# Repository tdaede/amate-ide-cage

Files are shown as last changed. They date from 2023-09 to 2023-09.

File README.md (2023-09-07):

This is a PCB for the NEC PC-9821 A-Mate series hard drive caddies, e.g. the NEC PC-9821A-E07 or ICM INTER-340A.

The PCB is mechanically compatible, though note that the IDE cable is reversed comapred to the NEC board! NEC uses a ribbon cable with the connector crimped on backwards. This PCB is instead marked for a standard, straight through IDE cable. The connector can still be installed reversed if desired, or a right angle connector could be used for e.g. a CF card adapter.

Also note that the 74HCT157s are in a narrow SO package rather than the more common SOIC.

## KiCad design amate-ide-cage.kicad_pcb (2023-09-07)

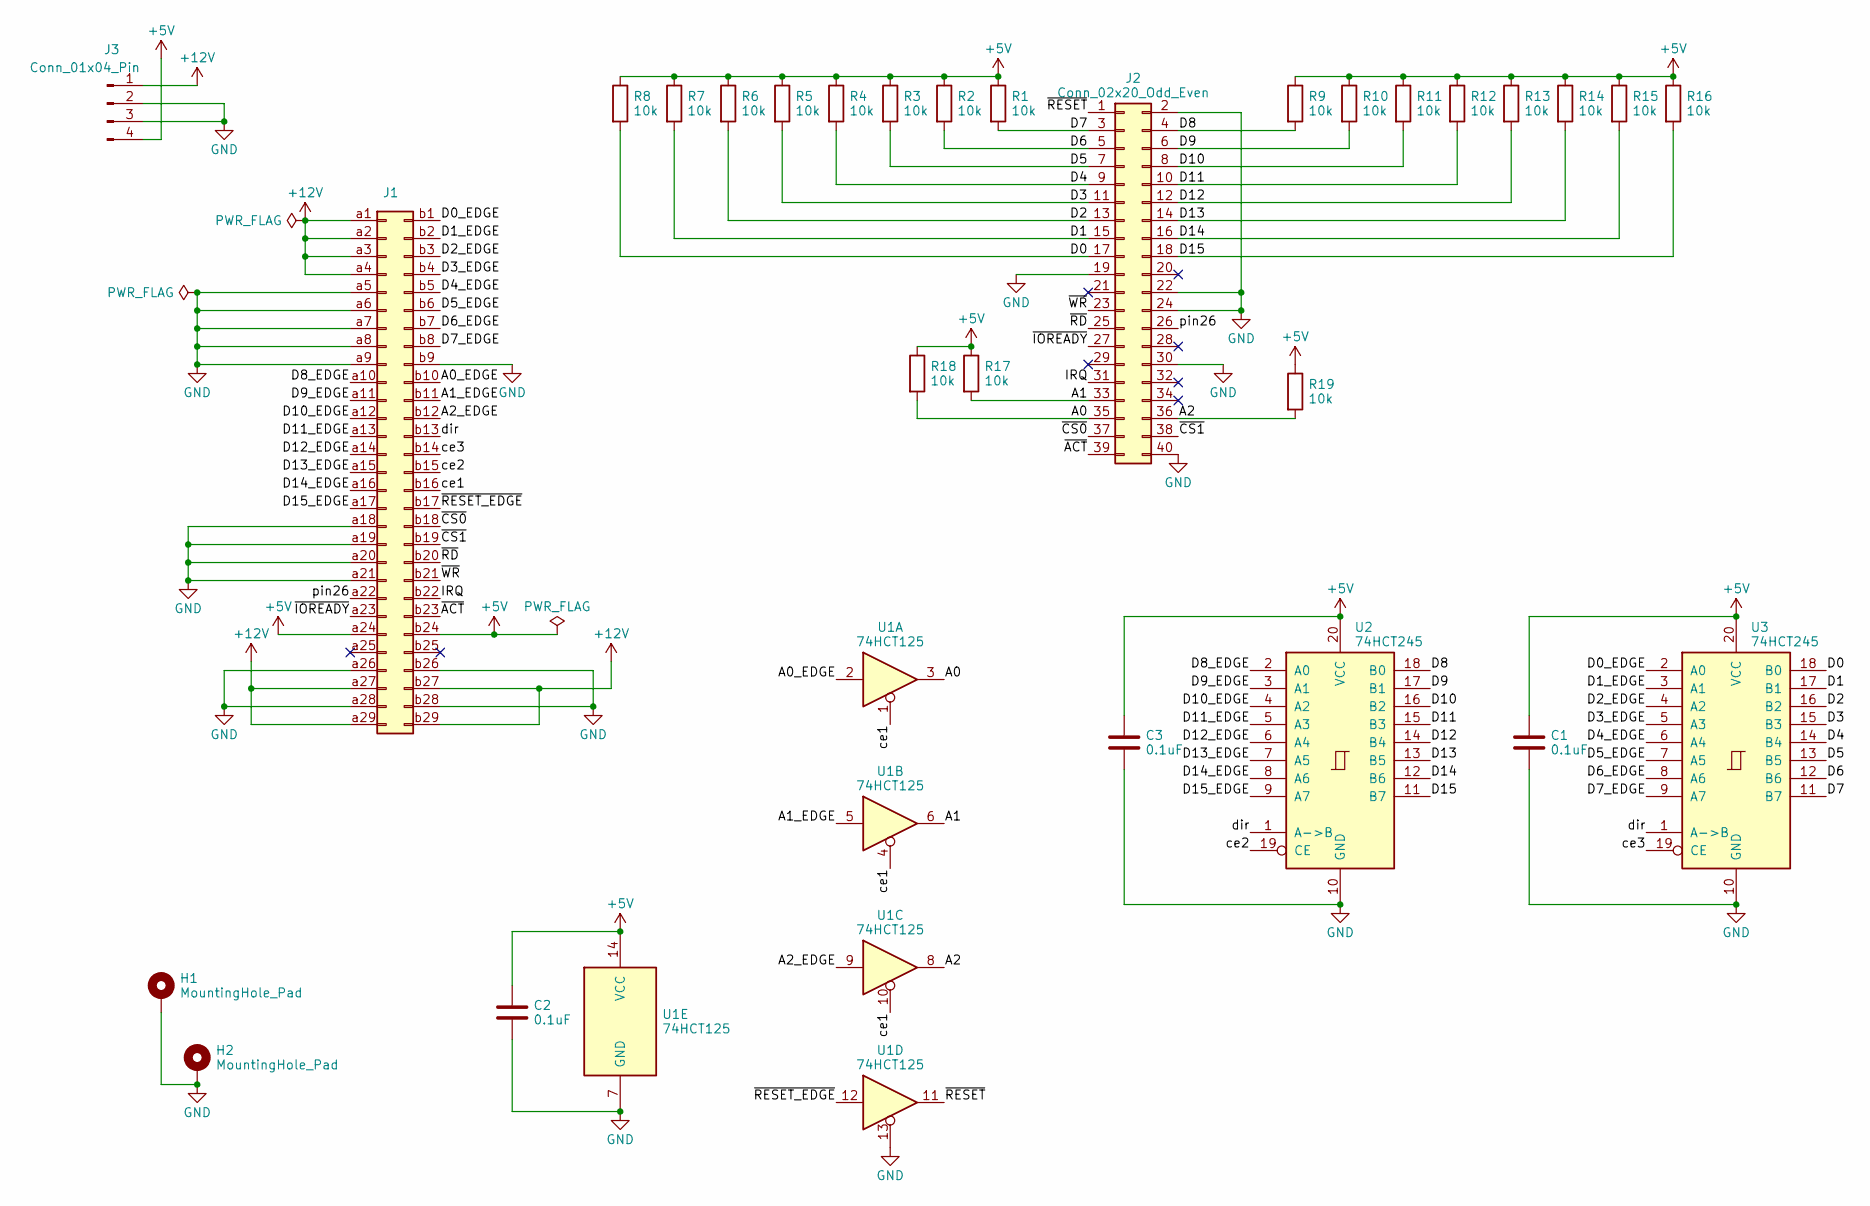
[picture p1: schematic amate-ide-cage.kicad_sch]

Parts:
C1, C2, C3: 0.1uF; C_0603_1608Metric; Digikey 311-1341-1-ND
H1, H2: MountingHole_Pad; MountingHole_3mm_Pad; Digikey DNP
J1: amate_ide_edge; Digikey DNP
J2: Conn_02x20_Odd_Even; IDC-Header_2x20_P2.54mm_Vertical; Digikey S9175-ND
J3: Conn_01x04_Pin; Molex_KK-396_5273-04A_1x04_P3.96mm_Vertical; Digikey WM4622-ND
R1, R2, R3, R4, R5, R6, R7, R8, R9, R10, R11, R12, R13, R14, R15, R16, R17, R18, R19: 10k; R_0603_1608Metric; Digikey 311-10.0KHRCT-ND
U1: 74HCT125; SOIC-14_3.9x8.7mm_P1.27mm; Digikey 1727-2834-1-ND
U2, U3: 74HCT245; SO-20_5.3x12.6mm_P1.27mm; Digikey 296-15849-1-ND

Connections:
+5V: C1.1, C2.1, C3.1, J1.a24, J1.b24, J3.4, R1.1, R2.1, R3.1, R4.1, R5.1, R6.1, R7.1, R8.1, R9.1, R10.1, R11.1, R12.1, R13.1, R14.1, R15.1, R16.1, R17.1, R18.1, R19.1, U1.14 (VCC), U2.20 (VCC), U3.20 (VCC)
+12V: J1.a1, J1.a2, J1.a3, J1.a4, J1.a27, J1.a29, J1.b27, J1.b29, J3.1
/A0: J2.35, R18.2, U1.3
/A0_EDGE: J1.b10, U1.2
/A1: J2.33, R17.2, U1.6
/A1_EDGE: J1.b11, U1.5
/A2: J2.36, R19.2, U1.8
/A2_EDGE: J1.b12, U1.9
/D0: J2.17, R8.2, U3.18 (B0)
/D0_EDGE: J1.b1, U3.2 (A0)
/D1: J2.15, R7.2, U3.17 (B1)
/D1_EDGE: J1.b2, U3.3 (A1)
/D2: J2.13, R6.2, U3.16 (B2)
/D2_EDGE: J1.b3, U3.4 (A2)
/D3: J2.11, R5.2, U3.15 (B3)
/D3_EDGE: J1.b4, U3.5 (A3)
/D4: J2.9, R4.2, U3.14 (B4)
/D4_EDGE: J1.b5, U3.6 (A4)
/D5: J2.7, R3.2, U3.13 (B5)
/D5_EDGE: J1.b6, U3.7 (A5)
/D6: J2.5, R2.2, U3.12 (B6)
/D6_EDGE: J1.b7, U3.8 (A6)
/D7: J2.3, R1.2, U3.11 (B7)
/D7_EDGE: J1.b8, U3.9 (A7)
/D8: J2.4, R9.2, U2.18 (B0)
/D8_EDGE: J1.a10, U2.2 (A0)
/D9: J2.6, R10.2, U2.17 (B1)
/D9_EDGE: J1.a11, U2.3 (A1)
/D10: J2.8, R11.2, U2.16 (B2)
/D10_EDGE: J1.a12, U2.4 (A2)
/D11: J2.10, R12.2, U2.15 (B3)
/D11_EDGE: J1.a13, U2.5 (A3)
/D12: J2.12, R13.2, U2.14 (B4)
/D12_EDGE: J1.a14, U2.6 (A4)
/D13: J2.14, R14.2, U2.13 (B5)
/D13_EDGE: J1.a15, U2.7 (A5)
/D14: J2.16, R15.2, U2.12 (B6)
/D14_EDGE: J1.a16, U2.8 (A6)
/D15: J2.18, R16.2, U2.11 (B7)
/D15_EDGE: J1.a17, U2.9 (A7)
/IRQ: J1.b22, J2.31
/ce1: J1.b16, U1.1, U1.4, U1.10
/ce2: J1.b15, U2.19 (CE)
/ce3: J1.b14, U3.19 (CE)
/dir: J1.b13, U2.1 (A->B), U3.1 (A->B)
/pin26: J1.a22, J2.26
/~ACT: J1.b23, J2.39
/~CS0: J1.b18, J2.37
/~CS1: J1.b19, J2.38
/~IOREADY: J1.a23, J2.27
/~RD: J1.b20, J2.25
/~RESET_EDGE: J1.b17, U1.12
/~RESET: J2.1, U1.11
/~WR: J1.b21, J2.23
GND: C1.2, C2.2, C3.2, H1.1, H2.1, J1.a5, J1.a6, J1.a7, J1.a8, J1.a9, J1.a18, J1.a19, J1.a20, J1.a21, J1.a26, J1.a28, J1.b9, J1.b26, J1.b28, J2.2, J2.19, J2.22, J2.24, J2.30, J2.40, J3.2, J3.3, U1.7 (GND), U1.13, U2.10 (GND), U3.10 (GND)

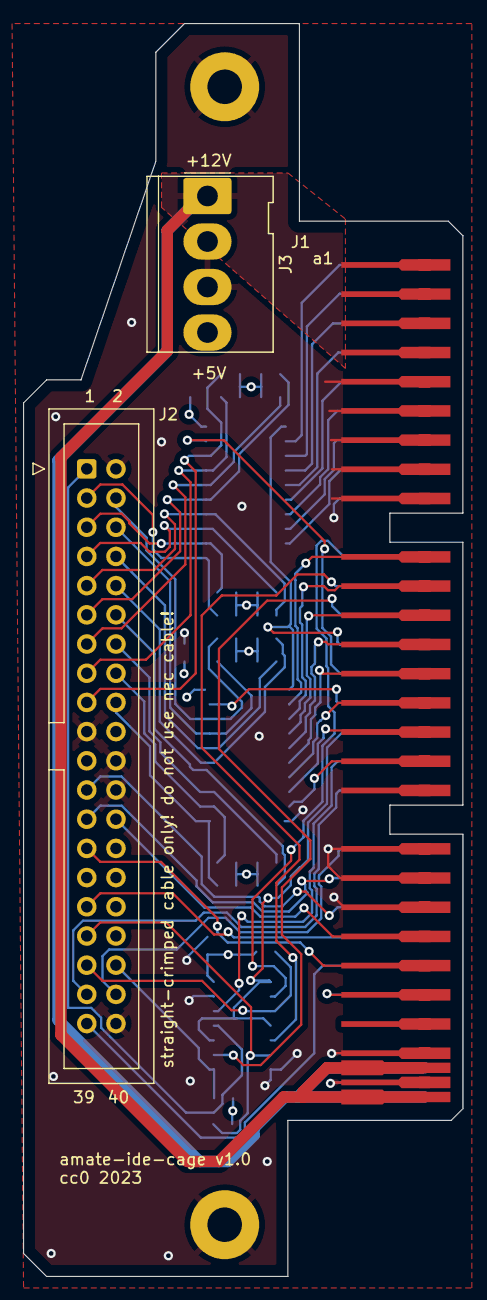
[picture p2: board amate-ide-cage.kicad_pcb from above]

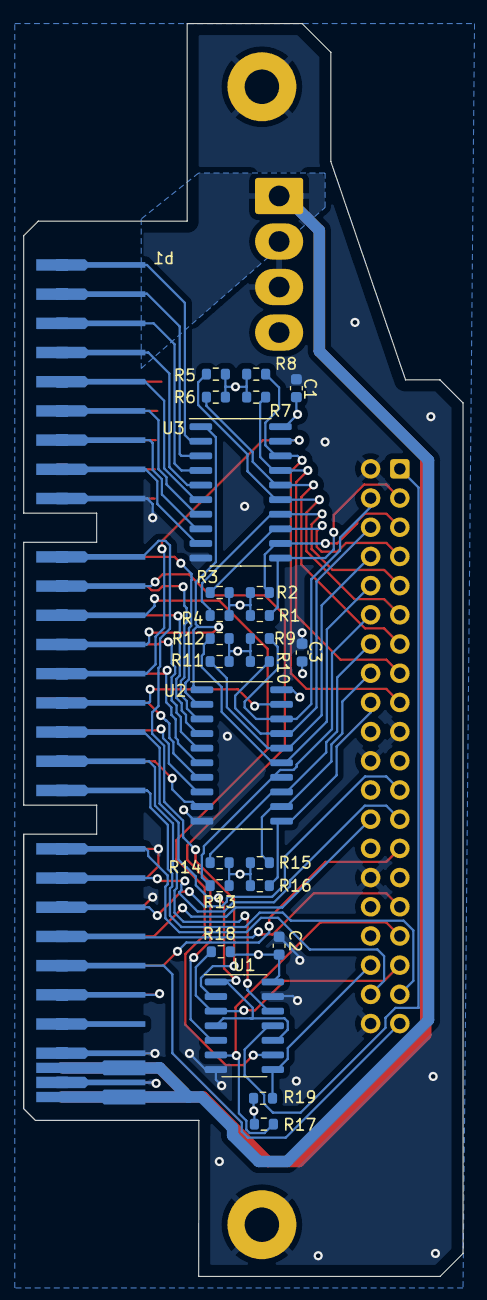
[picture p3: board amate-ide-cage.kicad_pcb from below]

Board: 4 copper layers, 38.2 x 109.0 mm, 30 parts (25 on the bottom side), 55 nets.
